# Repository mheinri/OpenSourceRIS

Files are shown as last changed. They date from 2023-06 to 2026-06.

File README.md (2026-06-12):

# Open Source RIS
An open source linearly polarized Reconfigurable Intelligent Surface (RIS) with 1-bit phase control for the frequency range of 5 GHz WiFi (5.15 - 5.875 GHz).

<p align="center">
  Open source RIS
  <br />
  Fig. 1: Open source RIS with 16×16=256 elements, front side
</p>

<p align="center">
  RIS backside
  <br />
  Fig. 2: Back side of the RIS with controller board attached
</p>

## Commercially Available Version
> [!NOTE]
> Due to the many inquiries we have received: An improved, ready-to-use version
> of this RIS for teaching, research, and development is commercially available
> from our startup **[NovoFlect](https://www.novoflect.de/en/)**.

- **Fully assembled, tested, and verified** - no need to deal with component
  sourcing, PCB procurement, assembly, soldering, or firmware flashing.
- **Compact variant** with 120 elements available.
- **Other frequency ranges** available as well, e.g. 3.6 GHz with 3-bit phase
  resolution or 28 GHz.
- Interested? Feel free to reach out via the contact form on our website:
  **[www.novoflect.de/en/contact](https://novoflect.de/en/contact/)**

## Unit Cell Design
The RIS unit cell consists of a linearly polarized pin-fed patch antenna, realized on a printed circuit board (PCB). Low-cost FR4 substrate with a specified dielectric constant of ϵr = 4.6 and dissipation factor tan δ = 0.028 is used. Fig. 3 shows the simplified unit cell with its dimensions. The circuit network generates a binary switchable reflection coefficient by using a BGS12P2L6 single pole, double throw (SPDT) RF switch from Infineon Technologies.

<p align="center">
  Simplified unit cell
  <br />
  Fig. 3: Simplified unit cell
</p>

## Surface Reflection Coefficient
The surface reflection coefficient of the RIS is measured with a vector network analyzer. During the measurement, the RIS is located in the aperture of a large horn antenna, which is specially designed for surface reflection coefficient measurements. Thus, the propagation vectors of the incident and reflected waves are perpendicular to the surface (normal incidence and reflection). Measuremetns are done for the two states where all elements are turned OFF or ON. A metal plate in size of the RIS is used for normalization of the measuements.
<p align="center">
  Measurement setup
  <br />
  Fig. 4: Setup for measurement of surface reflection coefficient
</p>

Fig. 5 shows the magnitude of the measured reflection coefficient. In the WiFi frequency bands from 5.15 - 5.875 GHz, the worst case surface reflection coefficient is −5.2 dB at 5.56 GHz for the OFF state and −4.8 dB at 5.15 GHz for the ON state.
<p align="center">
  Magnitude response
  <br />
  Fig. 5: Magnitude response
</p>

Fig. 6 shows the measured phase response as well as the phase difference between the all ON and all OFF states. The phase difference is wrapped to values between 0° and 180° and reaches its maximum at 5.53 GHz. It is worse at 5.875 GHz with a value of 92°.
<p align="center">
  Simplified unit cell
  <br />
  Fig. 6: Phase response and phase difference
</p>

## Power Supply
Power is supplied either via USB or via an external voltage source, e.g. a power supply unit, a battery or a rechargeable accumulator. The external voltage can be supplied via a coaxial power connector (2.1 x 5.5 mm), where the positive potential is applied to the inner pin of the connector. The recommended voltage range is between 9 V and 24 V DC. Power consumption with all elements ON as approx. 2 W.

The external voltage can be measured and read out, see documentation of the corresponding command below. This can be used, for example, to monitor the charge level of a battery.

## Control Interfaces
A controller board is attached to the back side of the RIS. With this, the RIS can be connected to a PC and controlled via a USB connection. Alternatively, it can be operated wirelessly with a battery and controlled via Bluetooth Low Energy (BLE). Fig. 7 shows the block diagram of the control unit.

<p align="center">
  Block diagram
  <br />
  Fig. 7: Block diagram
</p>

### USB interface
When using the USB interface, a virtual COM port (VCP) driver for the FT231XS USB-to-UART converter has to be installed. If the driver is not already installed or does not install automatically, it can be downloaded from the homepage of manufacturer FTDI (currently available at [https://ftdichip.com/drivers/vcp-drivers/](https://ftdichip.com/drivers/vcp-drivers/)). The VCP driver is provided for Windows, Linux and Mac OS.

Settings for the virtual COM port are as follows:
* 8 data bits
* 0 parity bits
* 1 stop bit
* 115.2 kBd/s

### BLE interface
A Proteus-III Bluetooth module from Würth Elektronik is used for control via Bluetooth. This is configured as a Bluetooth peripheral and must be coupled with a Bluetooth central, for example a PC with a Bluetooth interface installed. If the RIS is supplied with power, a new Bluetooth device appears in the search list of the PC. The device identifier or Bluetooth name of the RIS has the format A-xxxxxx, where xxxxxx stands for three bytes of the MAC address of the Bluetooth module in hexadecimal format (e.g. A-3163D1). These three bytes can be taken from the label on the Bluetooth module as "ID". The green LED next to the Bluetooth module flashes as long as the module has not been paired and is in advertising mode.

If pairing is started, a Static Pass Key must be entered. That Key hast to be set in advance via the USB interface and the `!BT-Key` command described below. If the pairing was successful, the green LED next to the Bluetooth module lights up permanently.

After pairing, the write and read services of the Bluetooth protocol must be activated in order to exchange data with the Bluetooth module. Once the services have been activated, the red LED next to the Bluetooth module lights up continuously. How exactly the services are activated depends on the software used to control the Bluetooth interface on the PC. Example code for MATLAB is provided under [Software/Control Software/MATLAB Code Examples](/Software/Control%20Software/MATLAB%20Code%20Examples/).

### Command syntax
All commands are ASCII encoded and are therefore easy to read. Each command starts with an exclamation mark (`!`) or a question mark (`?`) as start character followed by the actual command content. The command is then terminated at the end with a newline character (`␤`). A response from the RIS starts with a number sign (`#`) and is terminated with a newline cahracter as well. It is not necessary to be case sensitive with commands.

The following commands are available:
* Setting a pattern: `!0x...`
* Reading the currently configured pattern: `?Pattern`
* Reading the external supply voltage: `?Vext`
* Reading the serial number: `?SerialNo`
* Resetting the RIS: `!Reset`
* Setting the Static Pass Key for Bluetooth: `!BT-Key`

#### Setting a pattern
Each RIS element has been assigned a number between 1 and 256. Looking at the front of the surface as in Fig. 1, the first element is located in the top left corner. The other elements are arranged in reading direction with ascending number.
Examples: The second element is to the right of the first element, the 16th element is in the top right corner, the 17th element is on the far left in the second row from the top, and the 256th element is the one in the bottom right corner.
Essentially, a 256-bit number is sent to the RIS as a control command. Here, each bit represents the state of a specific RIS element. With a 0, the corresponding element is deactivated and the LED on the back is not lit and with a 1, the element is activated and the LED lights up. The assignment of the bit indices to the unit cells can be taken from the table below.

|Bit-Index|255 (MSB)|254|253|...|2|1|0 (LSB)|
|---|---|---|---|---|---|---|---|
|**Element no.**|1|2|3|...|254|255|256|

The control command for setting a pattern is formed on the basis of this 256-bit number. The command starts with an exclamation mark (`!`) as start character, followed by the 256-bit number in hexadecimal format. The hex prefix (`0x`) is specified at the beginning for better readability. The command is then terminated with a newline character (`␤`) at the end.

|Example Command|Set Pattern|
|---|---|
|`!0x0000000000000000000000000000000000000000000000000000000000000000␤`|All elements inactive|
|`!0xFFFFFFFFFFFFFFFFFFFFFFFFFFFFFFFFFFFFFFFFFFFFFFFFFFFFFFFFFFFFFFFF␤`|All elements active|
|`!0x8000000000000000000000000000000000000000000000000000000000000000␤`|Element 1 active|
|`!0x0000000000000000000000000000000000000000000000000000000000000001␤`|Element 256 active|
|`!0xFF00FF00FF00FF00FF00FF00FF00FF00FF00FF00FF00FF00FF00FF00FF00FF00␤`|Left half of the RIS active|
|`!0xFFFFFFFFFFFFFFFFFFFFFFFFFFFFFFFF00000000000000000000000000000000␤`|Upper half of the RIS active|

If the pattern was set successfully, the RIS sends `#OK␤` as confirmation. If no response is sent by the RIS, either an invalid command was used or an error occurred. In this case, the configured pattern of the RIS remains unchanged.

#### Reading the currently configured pattern
To read out the currently set pattern, the command `?Pattern␤` is used. The RIS then responds with `#0X012...DEF␤`, where `012...DEF` is a hexadecimal 256-bit long number. The structure of this number is the same as for setting a pattern.

|Example Command|Example Response from RIS|
|---|---|
|`?Pattern␤`|`#0X00007FFE40025FFA500A57EA542A55AA55AA542A57EA500A5FFA40027FFE0000␤`|

#### Reading the external supply voltage
In order to read out the external supply voltage that is present at the coaxial power connector, the command `?Vext␤` is used. The RIS then responds with `#00.00 V␤`, where `00.00` is a fixed-point number for the measured voltage in Volts.

|Example Command|Example Response from RIS|
|---|---|
|`?Vext␤`|`#09.14 V␤`|

#### Reading the serial number
Reading the serial number of a RIS board is done by sending the `?SerialNo␤` command. The RIS then responds with `#SerNo: 123␤`, where `123` is a fixed length serial number of up to three digits. For serial numbers with less digits, leding spaces are transmitted as well.

|Example Command|Example Response from RIS|
|---|---|
|`?SerialNo␤`|`#SerNo:  12␤`|

#### Resetting the RIS
The RIS can be reset by sending the `!Reset` command. The microcontroller then performs a software reset. The RIS is back up as soon as a `#READY␤` is received at the end of the boot information.

An example full response of the RIS after resetting or power cycling is as follows:
```
␤
Open Source RIS␤
Firmware version: 1.1␤
Serial no.:  12␤
Row count: 16␤
Column count: 16␤
␤
#READY!␤
```

Note that an established Bluetooth connection gets lost during a reset, so that a reinitialization of the BLE connection is required.

#### Setting the Static Pass Key for Bluetooth
The Static Pass Key can only be set via the USB interface. This command cannot be executed via Bluetooth. The Static Pass Key is non-volatile and remains unchanged after power cycling the RIS or resetting it via the `!Reset` command.
To set the Static Pass Key, the command `!BT-Key=123456␤` is used, where `123456` is exemplary for the new Key. The Static Pass Key has a fixed length of six decimal digits, all of which must be specified. Valid is therefore a number between zero and 999999.

|Example Command|New Static Pass Key|
|---|---|
|`!BT-Key=000000␤`|000000|
|`!BT-Key=123456␤`|123456|
|`!BT-Key=054860␤`|054860|

If the Static Pass Key was set successfully, the RIS sends `#OK␤` as confirmation. If the RIS sends `#ERROR␤`, either an invalid key was specified or an error occurred. Time between sending the command and receiving the response may take several seconds.

## Publications
* M. Heinrichs, A. Sezgin and R. Kronberger, "Open Source Reconfigurable Intelligent Surface for the Frequency Range of 5 GHz WiFi," 2023 IEEE International Symposium On Antennas And Propagation (ISAP), Kuala Lumpur, Malaysia, 2023, pp. 1-2, [doi: 10.1109/ISAP57493.2023.10389095.](https://doi.org/10.1109/ISAP57493.2023.10389095)
* M. Heinrichs, F. Pirlet and R. Kronberger, "Measurement System and Methodology for RIS-Evaluation," 2023 IEEE International Symposium On Antennas And Propagation (ISAP), Kuala Lumpur, Malaysia, 2023, pp. 1-2, [doi: 10.1109/ISAP57493.2023.10388696.](https://doi.org/10.1109/ISAP57493.2023.10388696)

## Acknowledgment
Many thanks to the Institute of Electronic Circuits at Ruhr University Bochum for the extensive help with assembling the printed circuit boards.
This work was funded by the German Federal Ministry of Education and Research (BMBF) in the framework of Project MetaSec (Förderkennzeichen 16KIS1236).

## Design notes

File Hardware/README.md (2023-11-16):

# Manufacturing Information
Open Source RIS is designed for the JLC04161H-7628 impedance-controlled PCB stackup from JLCPCB ([jlcpcb.com](https://jlcpcb.com/)). It is highly recommended to use the same manufacturer and PCB stackup for the RF PCB in order to get comparable results! For the controller PCB any suitable 4-layer PCB stackup may be used.

Recommended PCB stackup is as follows:

|Copper-Layer|Material|Thickness|Layer Usage (RF PCB)|Layer Usage (Controller PCB)|
|-|-|-|-|-|
|1|Copper + gold plating|0.035 mm|Signals and components|Signals and components|
| |FR4 (7628 material)|0.210 mm| | |
|2|Copper|0.015 mm|Groundplane|Groundplane|
| |FR4 (core material)|1.065 mm| | |
|3|Copper|0.015 mm|Empty (copper removed)|+3.3 V|
| |FR4 (7628 material)|0.210 mm| | |
|4|Copper + gold plating|0.035 mm|Patches|Signals|

Dielectric constant of prepreg material and core material must be equal:
* Dielectric constant (according to manufacturer): 4.6
* Dielectric constant (measured and used for simulation): 4.8

PCB assembly was done in-house and not with JLCPCB assembly service. Small changes to the pick and place file format may be required for commercial assembly services.

# Settings for Ordering at JLCPCB
The following order options have been used when ordering from JLCPCB. Irrelevant options are omitted.
## RF PCB
* Base Material: FR4
* Layers: 4
* Dimension: 360 mm * 247 mm
* Product Type: Industrial/Consumer electronics
* Different Design: 1
* Delivery Format: Single PCB
* PCB Thickness: 1.6 mm
* Impedance Control: Yes JLC04161H-7628
* Material Type: TG155
* Via Covering: Tented
* Surface Finish: ENIG Gold Thickness 1 U'' (ENIG is preferred over HASL)
* Deburring/Edge routing: No
* Outer Copper Weight: 1 oz
* Inner Copper Weight: 0.5 oz
* Gold Fingers: No
* Flying Probe Test: Fully Test
* Castellated Holes: No
* Remove Order Number: Yes (but is not required)
* Min via hole size/diameter: 0.2 mm/(0.3/0.35 mm)
* 4-Wire Kelvin Test: Yes
* Paper between PCBs: Yes (but is not required)
* Appearance Quality: IPC Class 2 Standard
* Silkscreen Technology: Ink-Jet/Screen Printing Silkscreen
* Board Outline Tolerance: +/- 0.2 mm (Regular)

## Controller PCB
Same as above with Dimension 105 mm * 95 mm. Impedance controlled stackup is not required as the controller PCB is not relevant for the RF properties.

# Known Issue
It has been observed that in some cases the board-to-board connections do not work. Due to its large size, the RF PCB is not absolutely planar. By mounting the RIS, e.g. on an aluminum frame, the RF PCB bends. This affects the pin header connection, causing it to fail in some cases.

We have therefore soldered the controller PCB directly to the RF PCB by omitting the female pin heads. The distance between RF PCB and controller PCB should remain at least 3 mm to avoid undesirable effects on the RIS elements below.

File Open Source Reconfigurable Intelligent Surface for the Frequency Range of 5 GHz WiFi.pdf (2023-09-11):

# Open Source Reconfigurable Intelligent Surface for the Frequency Range of 5 GHz WiFi

Markus Heinrichs
High Frequency Laboratory
TH Koeln - University of Appl. Sciences Cologne, Germany
markus.heinrichs@th-koeln.de

Aydin Sezgin
Institute of Digital Communication Systems Ruhr University Bochum
Bochum, Germany
aydin.sezgin@rub.de

Rainer Kronberger
High Frequency Laboratory
TH Koeln - University of Appl. Sciences Cologne, Germany
rainer.kronberger@th-koeln.de

Abstract—Reconfigurable Intelligent Surfaces (RIS) have been identified as a potential ingredient to enhance the performance of contemporary wireless communication and sensing systems. Yet, most of the existing devices are either costly or not available for reproduction. To close this gap, a Reconfigurable Intelligent Surface for the frequency range of 5 GHz WiFi is presented in this work. We describe the designed unit cell, which is optimized for the full frequency range of 5.15 to 5.875 GHz. Standard FR4 substrate is used for cost optimization. The measured reflection coefficient of a rectangular RIS prototype with 256 elements is used for RF performance evaluation. Fabrication data and firmware source code are made open source, which makes RIS more available in real measurement setups.
Index Terms—Reconfigurable Intelligent Surface, RIS, unit cell, WiFi, open source
I. INTRODUCTION
Reconfigurable Intelligent Surfaces (RIS) are currently a major subject of research on wireless systems. Multiple potential application areas of RIS are being investigated around the world, from next generation cellular networks (6G) through unmanned aerial vehicle assisted systems to physical layer security systems [1] [2]. Nevertheless, the availability of RIS prototypes is still limited, which does not allow every research group to perform experiments in real measurement setups using RIS. In particular, the large amount of time required to develop a RIS can be a time-consuming and costly impediment. In order to facilitate the access to measurements with RIS, we have made our 5.5 GHz RIS design open source, similar to the OpenRIS for 3.5 GHz from [3]. The fabrication data is freely accessible and can be used without restriction, which enables everyone to build and utilize RIS. The frequency range of 5 to 6 GHz is chosen since measurements at sub-6 GHz frequencies are cost effective and widespread, not least because of their use in WiFi. The wavelength of approx. 55 mm at a center frequency of 5.5 GHz results in a size ratio that allows arrays with several hundred elements while at the same time being manufacturable with acceptable effort.
In the following, we describe our RIS unit cell and its principle of operation. Then we address the RF performance and present measurement results.

II. UNIT CELL
The RIS unit cell consists of a rectangular patch reflector above a ground plane. The patch on the front side is connected to the back side of the RIS by a plated through-hole connection (via), as in the case of a linearly polarized pin-fed patch antenna. We realized this by using a printed circuit board (PCB) with three copper layers, which can be manufactured externally in a standard process as a four-layered PCB with the second layer left empty. Thus, the unit cell can be implemented on a single PCB on which the components can be placed and soldered by machines, facilitating manufacturing. We used a low-cost FR4 substrate with a specified dielectric constant of ϵr = 4.6 and dissipation factor tan δ = 0.028. A cross sectional view of the unit cell and its dimensions are depicted

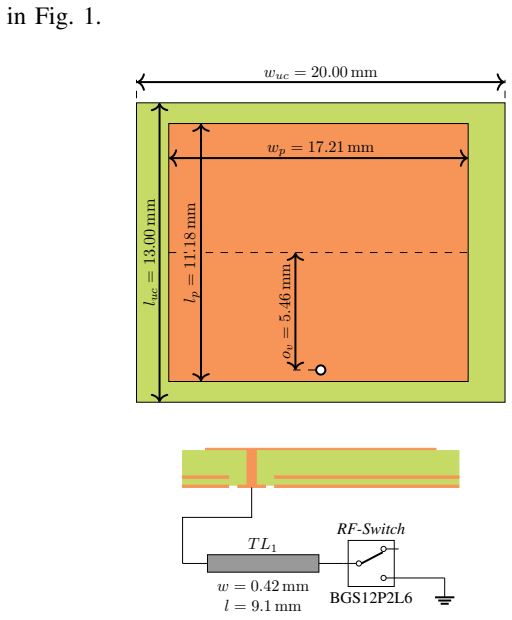
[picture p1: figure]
in Fig. 1.; wuc = 20.00 mm; luc = 13.00 mm; RF-Switch; BGS12P2L6

Fig. 1. Unit cell dimensions and schematic

The shown circuit network is located on the back side of the unit cell and generates a binary switchable reflection coefficient. For this we use a BGS12P2L6 single pole, double throw (SPDT) RF switch in CMOS technology from Infineon Technologies [4], which switches the antenna port to either an open or short circuit. In this way, a phase shift of 180◦ is achieved while keeping the DC power consumption of the RF switches at a low level. The microstrip transmission line

T L1 is used to tune the RF performance. Our unit cell is optimized for the WiFi frequency range of 5.15 to 5.875 GHz. This means, that the magnitude of the reflection coefficient of the surface should be as large as possible in both switching states, with the propagation direction of the incident and reflected wave being directed orthogonal to the surface (normal incidence and reflection). The phase difference between the two switching states is optimized to be as close as possible to the ideal value of 180◦ over the whole frequency range considered. By using these optimization goals, the resulting transmission line T L1 has a width of w = 0.42 mm and a length of l = 9.1 mm. Simulation and optimization of the unit cell is done in CST Microwave Studio using Floquet ports and frequency domain solver.
The fabricated RIS, which consists of 16 × 16 unit cells, is shown in Fig. 2. A controller PCB is attached to the backside. This allows the RIS to be connected to a PC and controlled via a USB connection. Alternatively, it can be operated wirelessly with a battery and controlled via Bluetooth Low Energy (BLE).

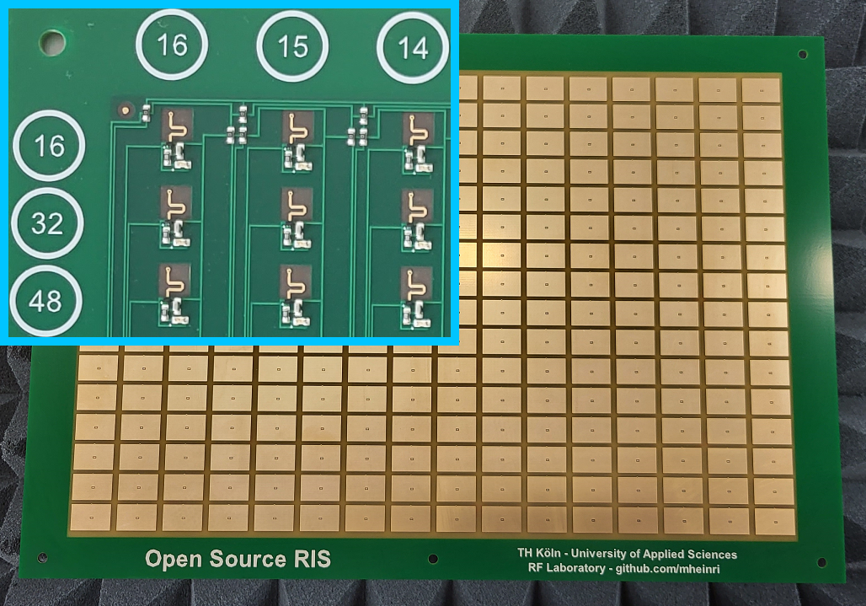
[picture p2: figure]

Fig. 2. RIS with 256 elements and sectional view of nine backside elements

III. RF MEASUREMENTS
The reflection coefficient of the RIS is measured with a vector network analyzer while the RIS is located in the aperture of a horn antenna, which is specially designed for the measurement of surface reflection coefficients. The magnitude of the measured surface reflection coefficient is shown in Fig. 3 (top). The measurement is normalized to the reflection of a metal plate in the size of the RIS. The corresponding phase as well as the phase difference between the two states in which all elements are turned OFF or ON are shown in Fig. 3 (bottom). The phase difference is wrapped to values between 0

◦

and 180◦
In the WiFi frequency bands, the minimum surface reflection coefficient is −5.2 dB at 5.56 GHz for the OFF state and −4.8 dB at 5.15 GHz for the ON state. This could be improved slightly by using low-loss RF substrate, however, with a significant increase of material costs. The phase difference reaches its maximum of 180◦
at 5.53 GHz and is minimal with

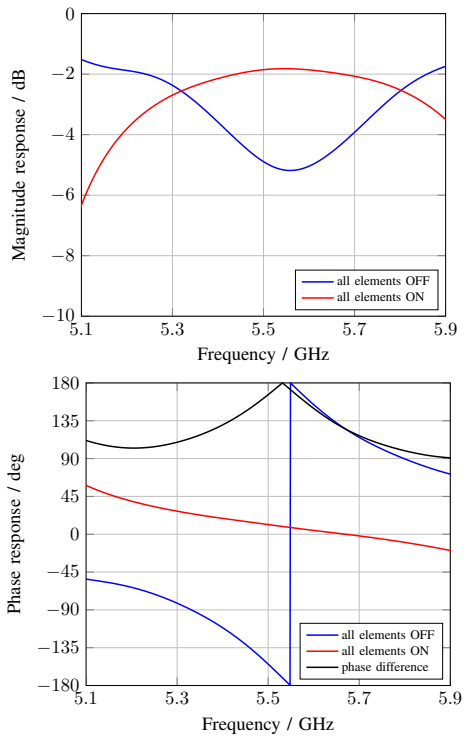
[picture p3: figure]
Frequency / GHz; Magnitude response / dB; all; elements OFF; elements ON; Phase response / deg; all phase difference

Fig. 3. Surface reflection coefficient (magnitude, phase and phase difference)

a value of 92◦
at 5.875 GHz. It is under current investigation how this phase behaviour performs in practical systems.

IV. CONCLUSION
We have presented an open source RIS for the frequency bands of 5 GHz WiFi. It offers a worse-case reflection coefficient of −5.2 dB and a phase response between 92◦ and
180◦ over the whole frequency range considered. The RIS is low cost and easy to manufacture. It can be controlled easily and is enabled for wireless usage. Fabrication data, firmware source code and additional documentation for the presented open source RIS are accessible at GitHub [5].
V. ACKNOWLEDGMENT
This work was funded by the German Federal Ministry of Education and Research (BMBF) in the framework of Project MetaSec (Forderkennzeichen 16KIS1235 and 16KIS1236). ¨

REFERENCES

[1] C. Pan et al., “Reconfigurable Intelligent Surfaces for 6G Systems: Principles, Applications, and Research Directions,” in IEEE Communications Magazine, vol. 59, no. 6, pp. 14-20, June 2021, doi: 10.1109/MCOM.001.2001076.
[2] Y. Li, C. Yin, T. Do-Duy, A. Masaracchia and T. Q. Duong, “Aerial Reconfigurable Intelligent Surface-Enabled URLLC UAV Systems,” in IEEE Access, vol. 9, pp. 140248-140257, 2021, doi: 10.1109/AC-CESS.2021.3119268.
[3] J. Rains, https://www.github.com/jimrains/OpenRIS, (accessed June 09 2023).
[4] Infineon Technologies, ”BGS12P2L6 - SPDT general purpose switch for high power applications”, BGS12P2L6 datasheet, Rev. 2.0, Jul. 2019.
[5] M. Heinrichs, https://www.github.com/mheinri, (accessed June 29 2023).

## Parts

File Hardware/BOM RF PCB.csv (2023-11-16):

Part | Value | Size | Quantity | Manufacturer | Manufacturer part number | Name
Pinhead | 2x2 | SMD RM1.27 | 2 | Würth Elektronik | 62100421021 | J1-2
Pinhead | 2x5 | SMD RM1.27 | 2 | Würth Elektronik | 62101021021 | J3-4
C | 1nF | 0603 | 256 | Würth Elektronik | 885012006029 | C001-256
C | 100nF | 0603 | 32 | Würth Elektronik | 885012206071 | C257-288
IC | 74HC595BQ | DHVQFN16 | 32 | Nexperia | 74HC595BQ,115 | IC257-288
LED | Green | 0603 | 256 | Würth Elektronik | 150060VS75000 | LED001-256
R | 0R | 0603 | 301 | Yageo | AC0603FR-070RL | R257-557
R | 1.5kR | 0603 | 256 | Yageo | RC0603FR-071K5L | R001-256
RF-Switch | BGS12P2L6 | TSLP-6 | 256 | Infineon | BGS12P2L6E6327XTSA1 | IC001-256

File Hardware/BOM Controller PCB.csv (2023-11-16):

Part | Value | Size | Quantity | Manufacturer | Manufacturer part number | Name
S | Switch | / | 1 | CTS | 222CMVABR | S101
X | Mini-USB connector | / | 1 | Würth Elektronik | 65100516121 | X202
X | DC-Jack | / | 1 | Würth Elektronik | 694106106102 | X201
Q | Crystal 25MHz | HC49UP | 1 | IQD | LFXTAL070480Reel | Q101
Pinhead | 1x06 | SMD RM2.54 | 1 | Amphenol FCI | 10129380-906002ALF | J101
Pinhead | 2x2 | RM 1.27 | 2 | Würth Elektronik | 62200421821 | J401, J402
Pinhead | 2x5 | RM 1.27 | 2 | Würth Elektronik | 62201021821 | J403, J404
LED | Yellow | 0603 | 1 | Würth Elektronik | 150060YS75000 | LED101
LED | Blue | 0603 | 1 | Würth Elektronik | 150060BS75000 | LED102
LED | Red | 0603 | 2 | Würth Elektronik | 150060RS75000 | LED201, LED301
LED | Green | 0603 | 2 | Würth Elektronik | 150060VS75000 | LED202, LED302
IC | LM1117IMP-3.3 | SOT223 | 1 | Texas Instruments | LM1117IMP-3.3/NOPB | IC203
IC | STM32F446RET6 | LQFP64 | 1 | STMicroelectronics | STM32F446RET6 | IC101
IC | FT231XS-R | SSOP20 | 1 | FTDI | FT231XS-R | IC202
IC | LM2596DSADJG | D˛PAK | 1 | onsemi | LM2596DSADJG | IC201
MOD | Protheus-III | / | 1 | Würth Elektronik | 2611011024000 | MOD301
D | SK33 | DO214AB | 4 | Micro Comm. Comp. | SK33-TP | D201, D202, D203, D204
L | Ferrite | 0805 | 3 | Würth Elektronik | 742792012 | L202, L301, L302
L | 100ľH | 8x8 | 1 | Würth Elektronik | 74404086101 | L201
C | 100ľF | 8x10.5 | 1 | Panasonic | EEH-ZA1V101V | C202
C | 680ľF | 8x11.9 | 1 | Panasonic | 16SVPK680M | C203
C | 10ľF | 1210 | 5 | Würth Elektronik | 885012209028 | C204, C209, C215, C216, C304
C | 4.7ľF | 0805 | 1 | TDK | C2012X7R1H475K125AC | C109
C | 1ľF | 0805 | 3 | AVX | 08051C105K4Z2A | C104, C106, C301
C | 100nF | 0603 | 15 | Würth Elektronik | 885012206071 | C103, C105, C107, C108, C110, C111, C201, C205, C207, C210, C213, C214, C217, C302, C305
C | 10nF | 0603 | 2 | Würth Elektronik | 885012206065 | C206, C208
C | 47pF | 0603 | 2 | Würth Elektronik | 885012006055 | C211, C212
C | 22pF | 0603 | 2 | Würth Elektronik | 885012006053 | C101, C102
C | 22pF | 0402 | 1 | Würth Elektronik | 885012005057 | C303
R | 0R | 0805 | 4 | Yageo | RC0805FR-070RL | R101, R102, R104, R105
R | 27R | 0603 | 2 | Yageo | RC0603FR-0727RL | R205, R206
R | 3.3kR | 0603 | 7 | Yageo | RC0603FR-073K3L | R107, R108, R204, R207, R208, R301, R302
R | 10kR | 0603 | 2 | Yageo | RC0603FR-0710KL | R103, R203
R | 13kR | 0603 | 1 | Yageo | RC0603FR-0713KL | R202
R | 91kR | 0603 | 1 | Yageo | RC0603FR-0791KL | R201

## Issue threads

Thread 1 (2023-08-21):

Regarding Hardware Design

DDS2144, 2023-08-21:
Dear Sir,

I'm currently working on hardware design using your repository and facing challenges. Could I kindly request your expert guidance on some queries? I've attached relevant files for your reference.

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
[Doubt-1 - Controller_PCB.xlsx](https://github.com/mheinri/OpenSourceRIS/files/12393408/Doubt-1.-.Controller_PCB.xlsx)
[Doubt-2 - Controller_PCB.xlsx](https://github.com/mheinri/OpenSourceRIS/files/12393409/Doubt-2.-.Controller_PCB.xlsx)
[Doubt-3 - RF_PCB.xlsx](https://github.com/mheinri/OpenSourceRIS/files/12393410/Doubt-3.-.RF_PCB.xlsx)
[Doubt-4 - RF_PCB.xlsx](https://github.com/mheinri/OpenSourceRIS/files/12393412/Doubt-4.-.RF_PCB.xlsx)

mheinri, 2023-08-21:
Hi DDS2144 ,
there is no information on the pinhead positions as they get populated by hand. This is beacuse these parts are through-hole components rather than SMD parts.
Resistor R106 is not populated at all (n.p.), thus there is no information in the BOM.
Fiducials are only used for automatic placement of components by the pick-and-place machine, so there is also no additional information on it required.
Hope this is helpful.
Best regards!

Closed 2023-08-21.

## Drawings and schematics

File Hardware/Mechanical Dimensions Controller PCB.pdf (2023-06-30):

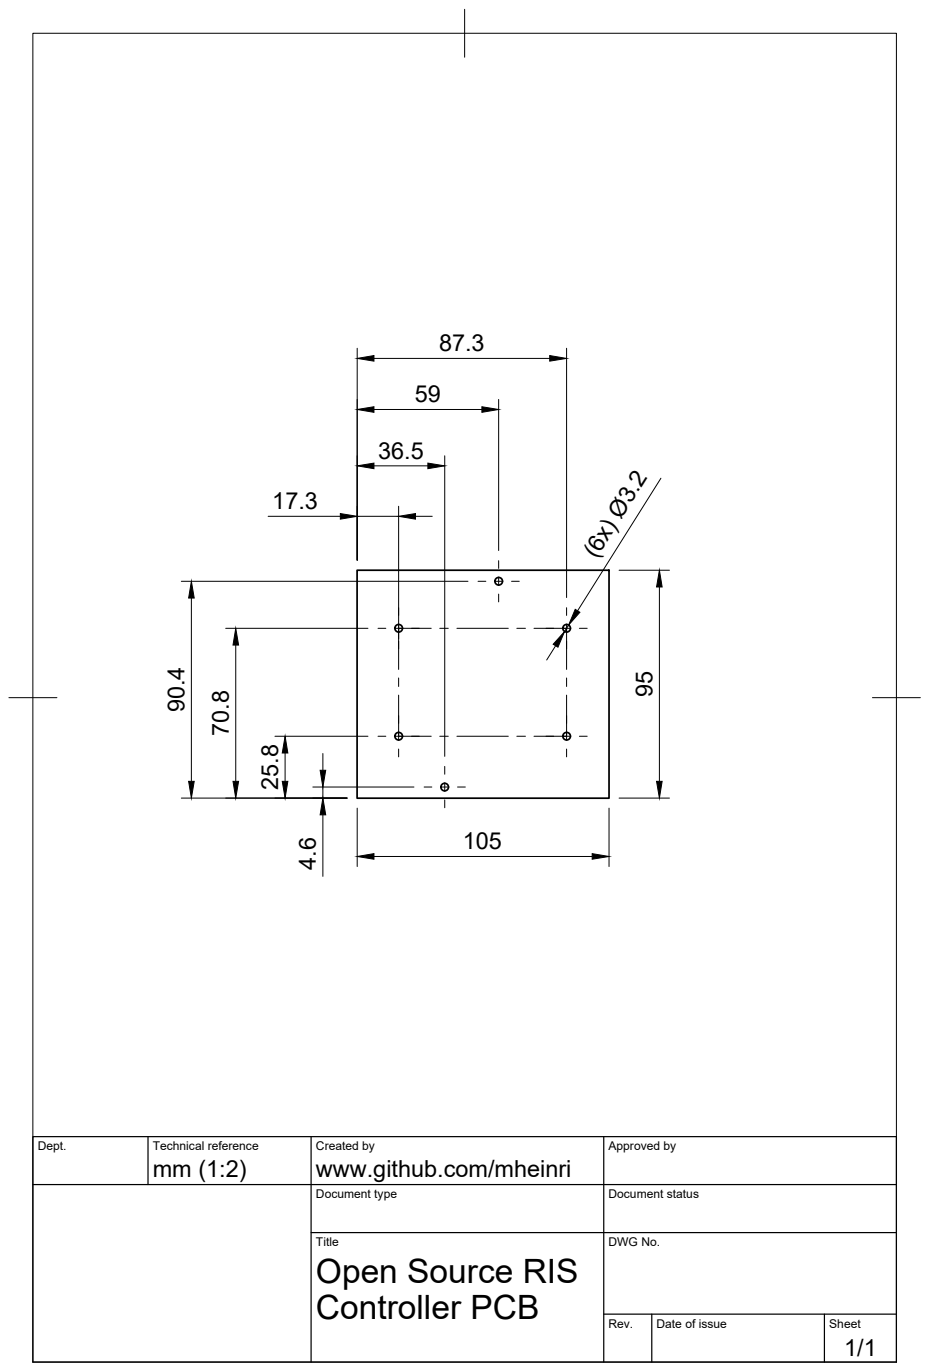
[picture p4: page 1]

Dept. | Technical reference mm (1:2) | Created by www.github.com/mheinri | Approved by

Document type | Document status

Title Open Source RIS Controller PCB | DWG No.

Rev. | Date of issue | Sheet 1/1

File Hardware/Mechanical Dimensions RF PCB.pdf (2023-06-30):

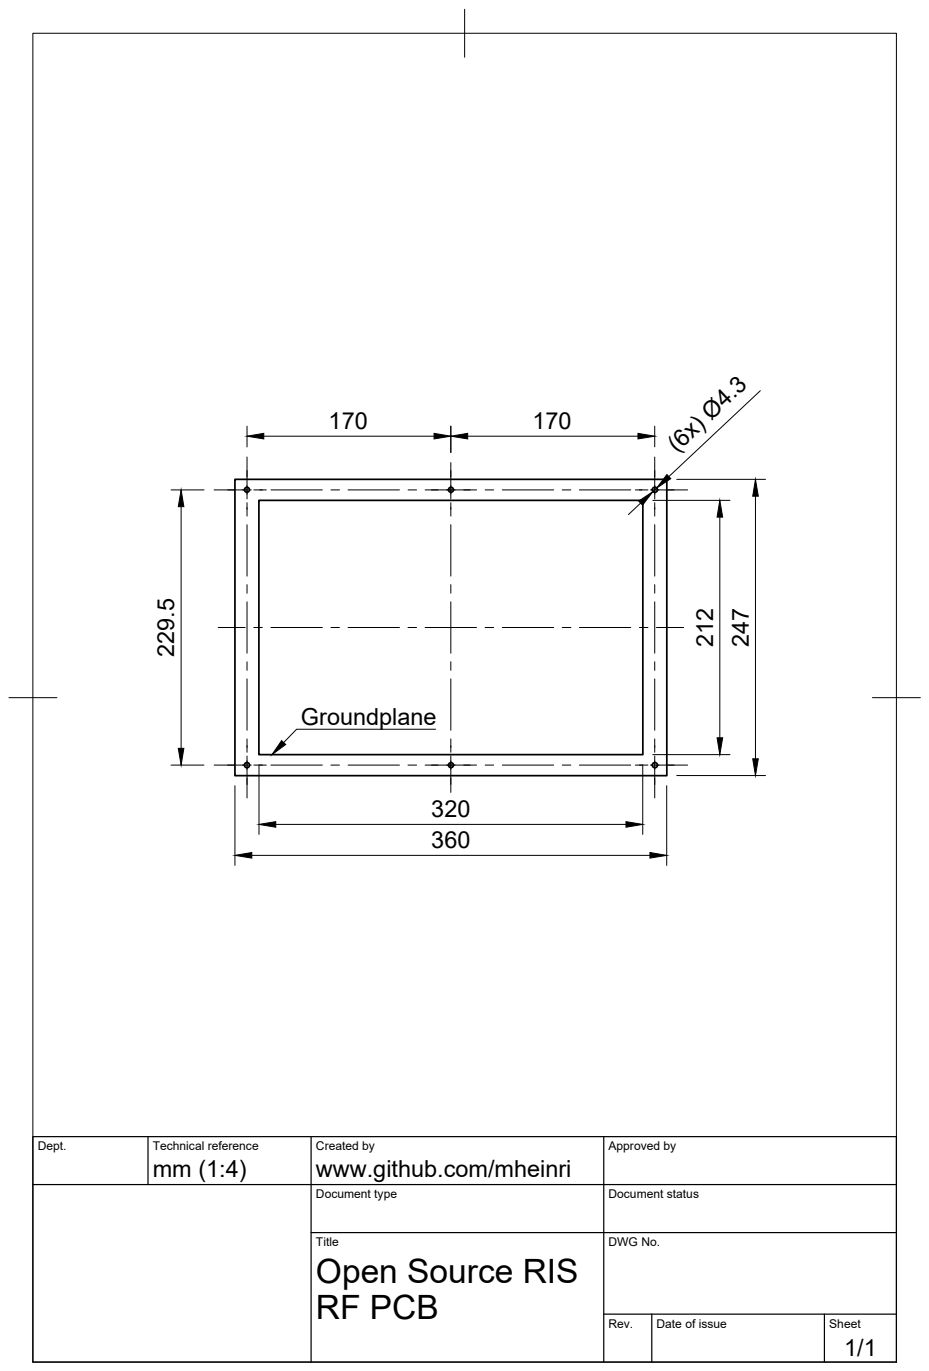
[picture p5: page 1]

Dept. | Technical reference mm (1:4) | Created by www.github.com/mheinri | Approved by

Document type | Document status

Title Open Source RIS RF PCB | DWG No.

Rev. | Date of issue | Sheet 1/1

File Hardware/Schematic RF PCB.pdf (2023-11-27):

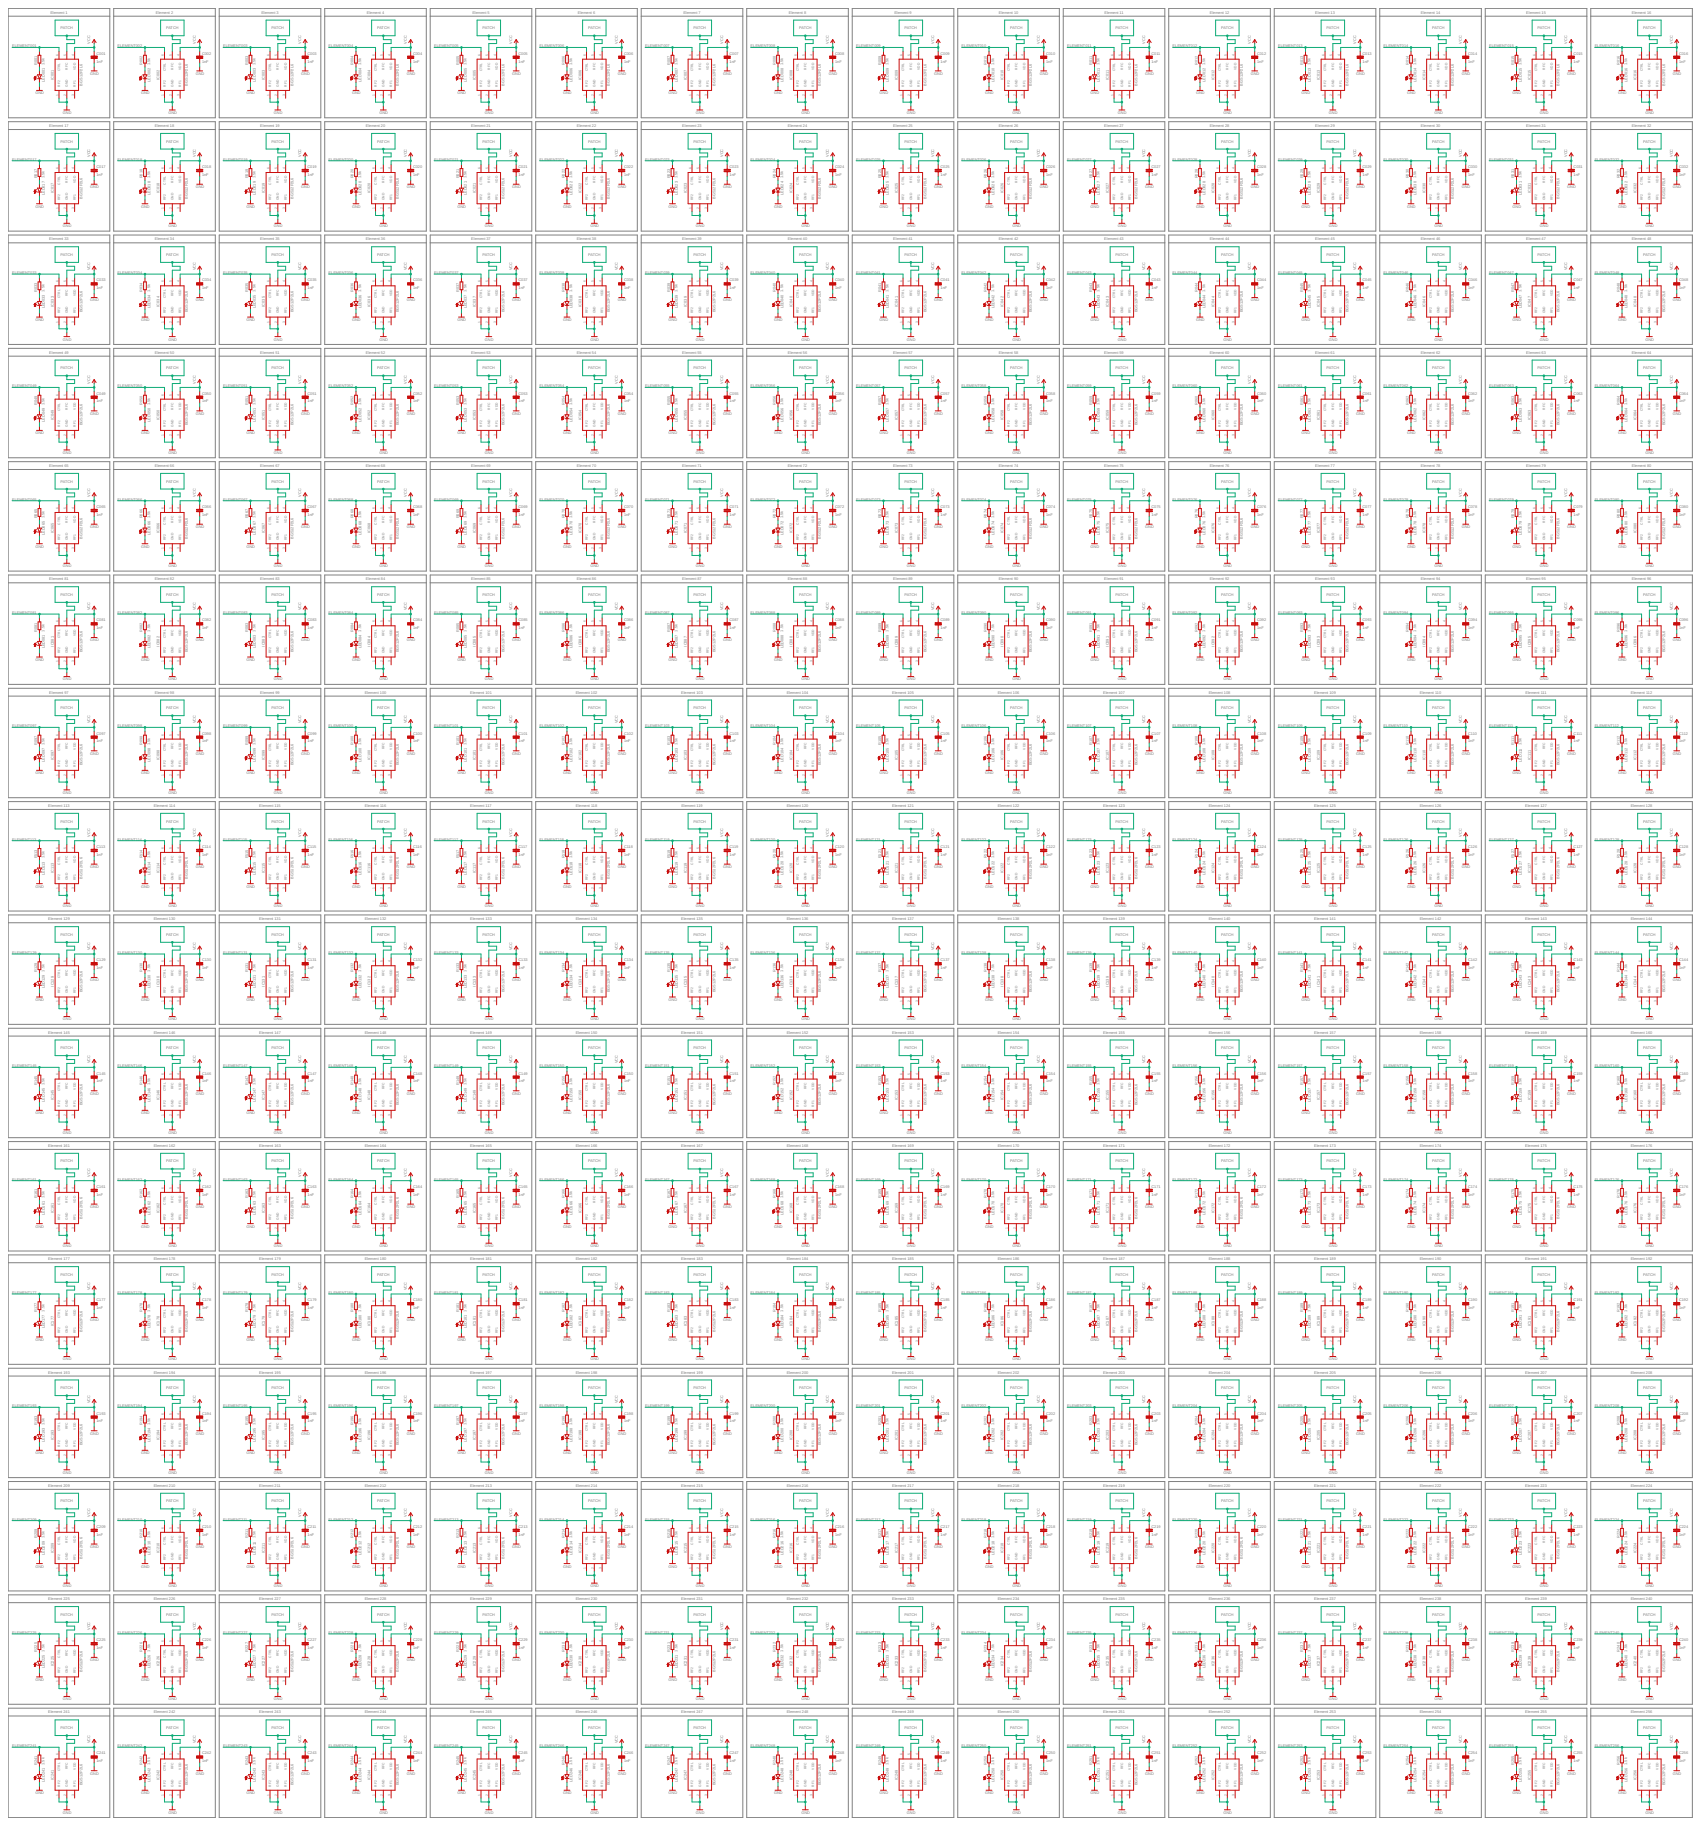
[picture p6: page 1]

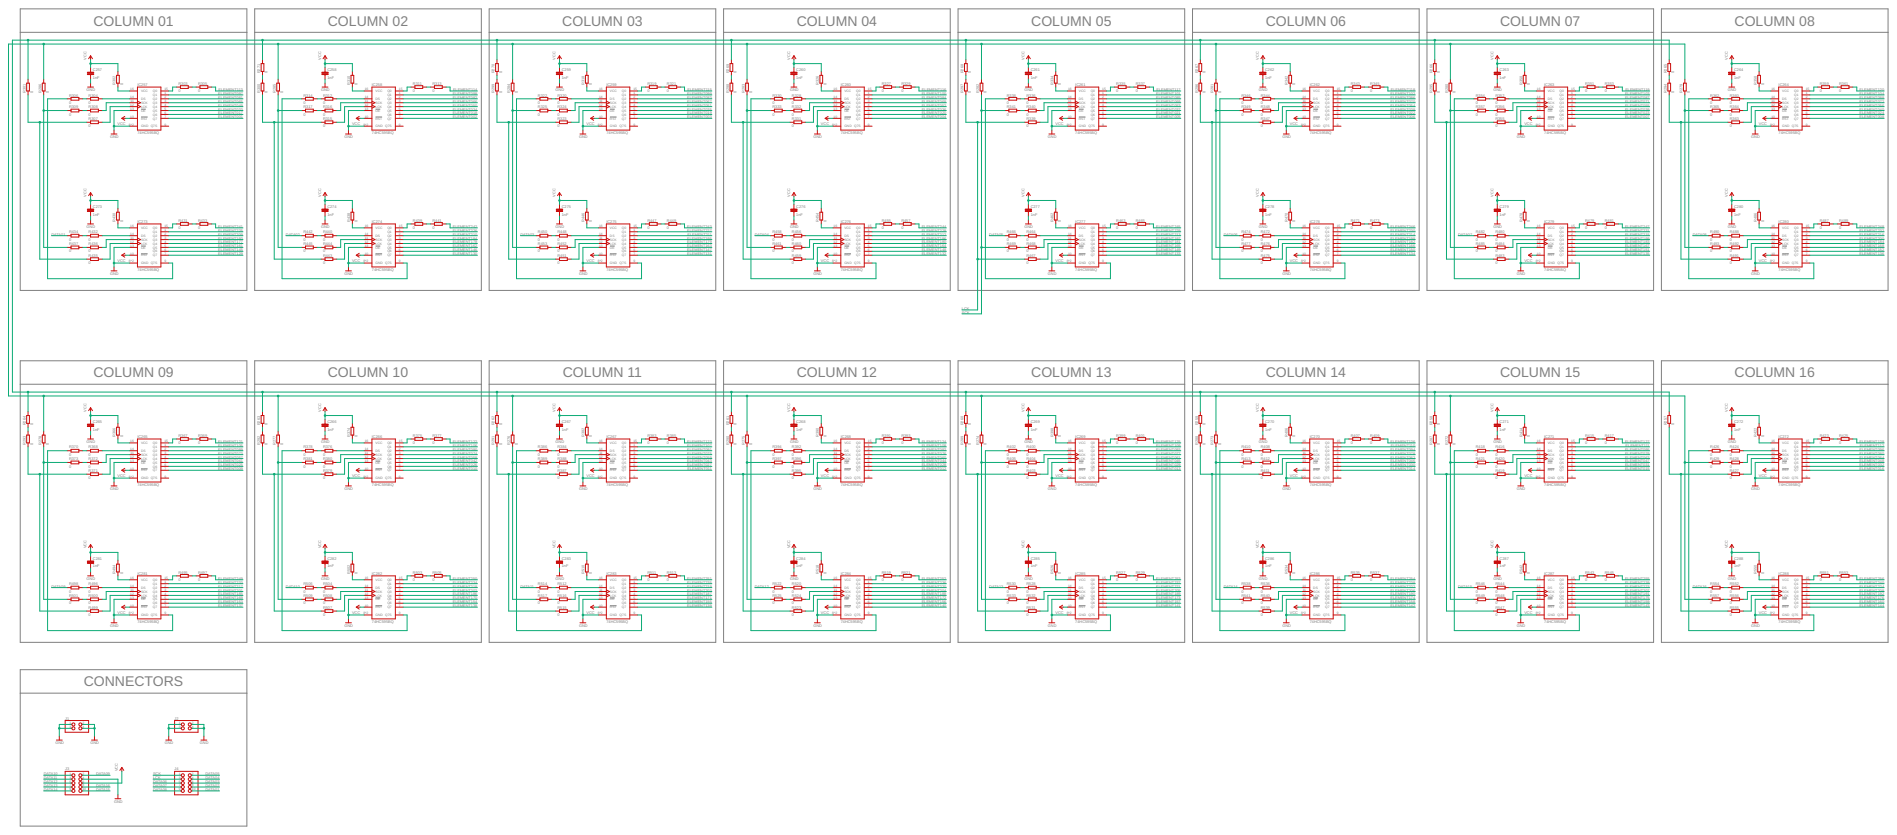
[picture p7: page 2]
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

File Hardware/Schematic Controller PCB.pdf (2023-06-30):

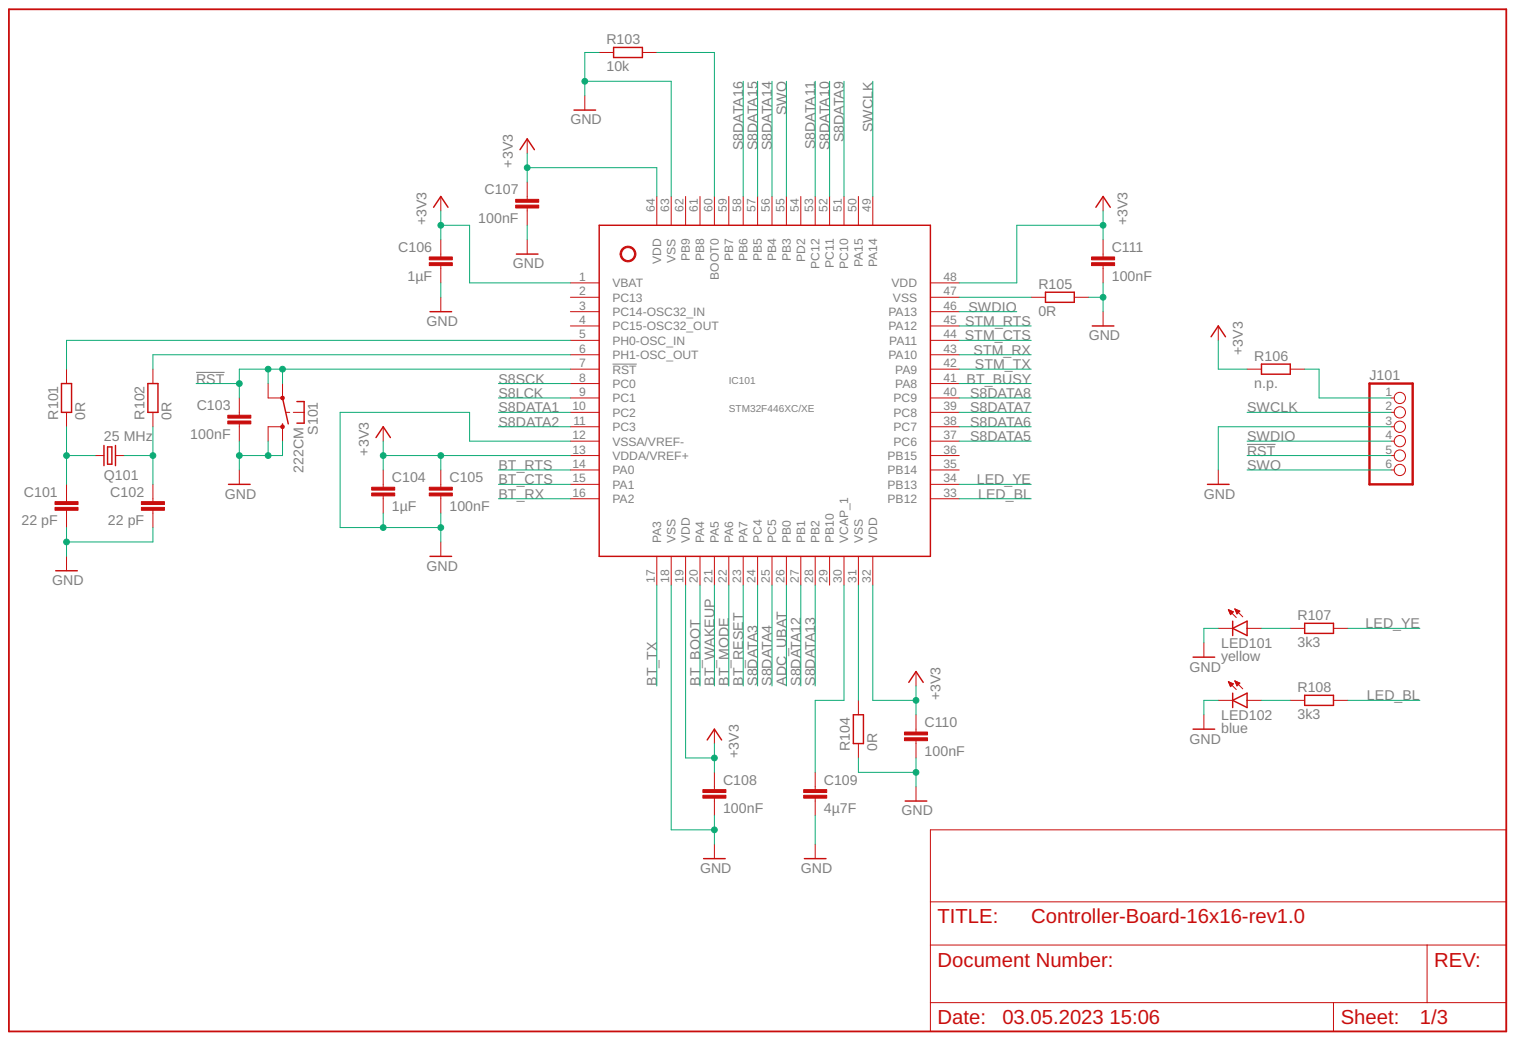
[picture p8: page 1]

Document Number: | REV:

Date: 03.05.2023 15:06 | Sheet: 1/3

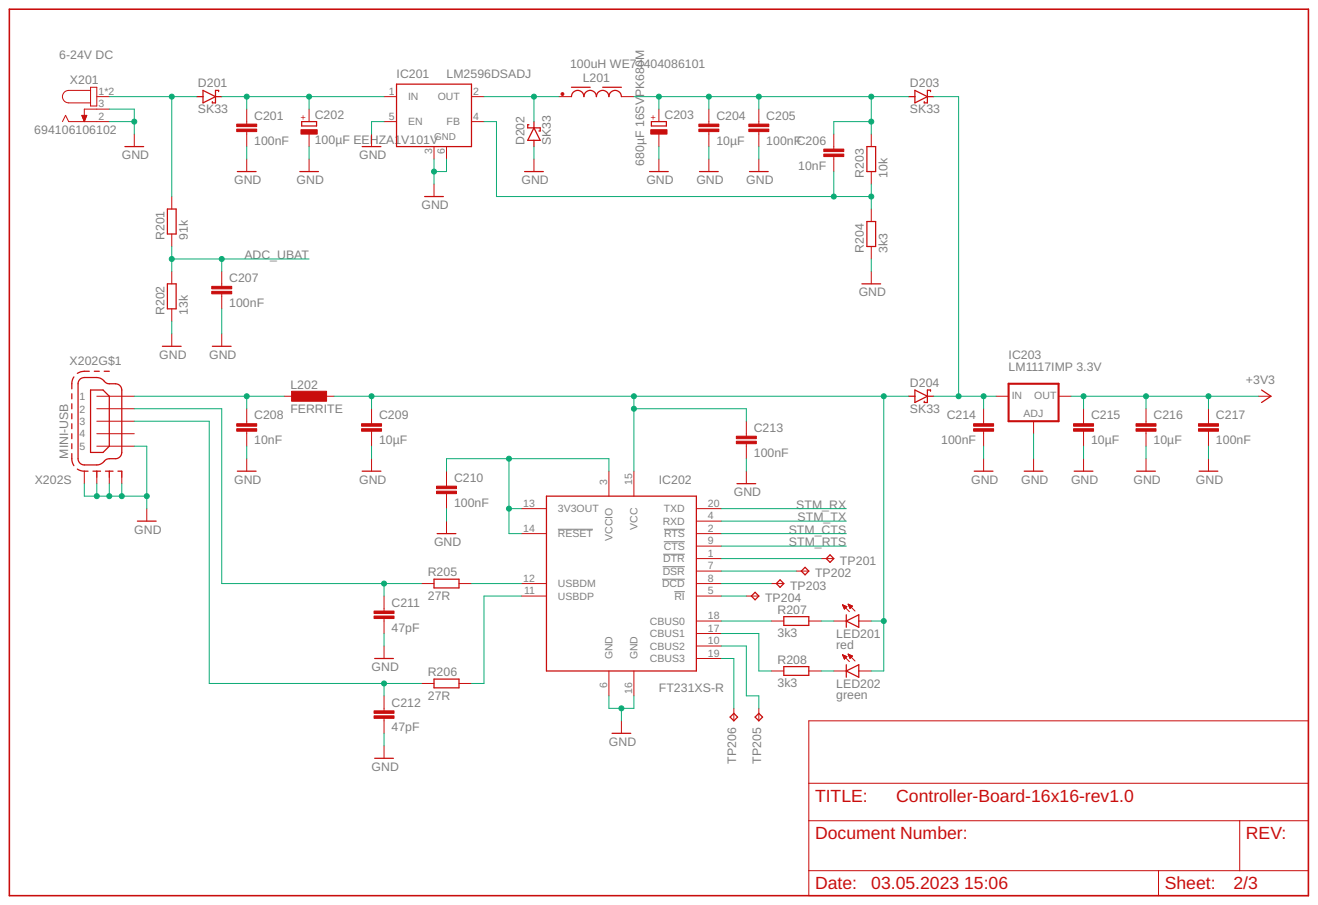
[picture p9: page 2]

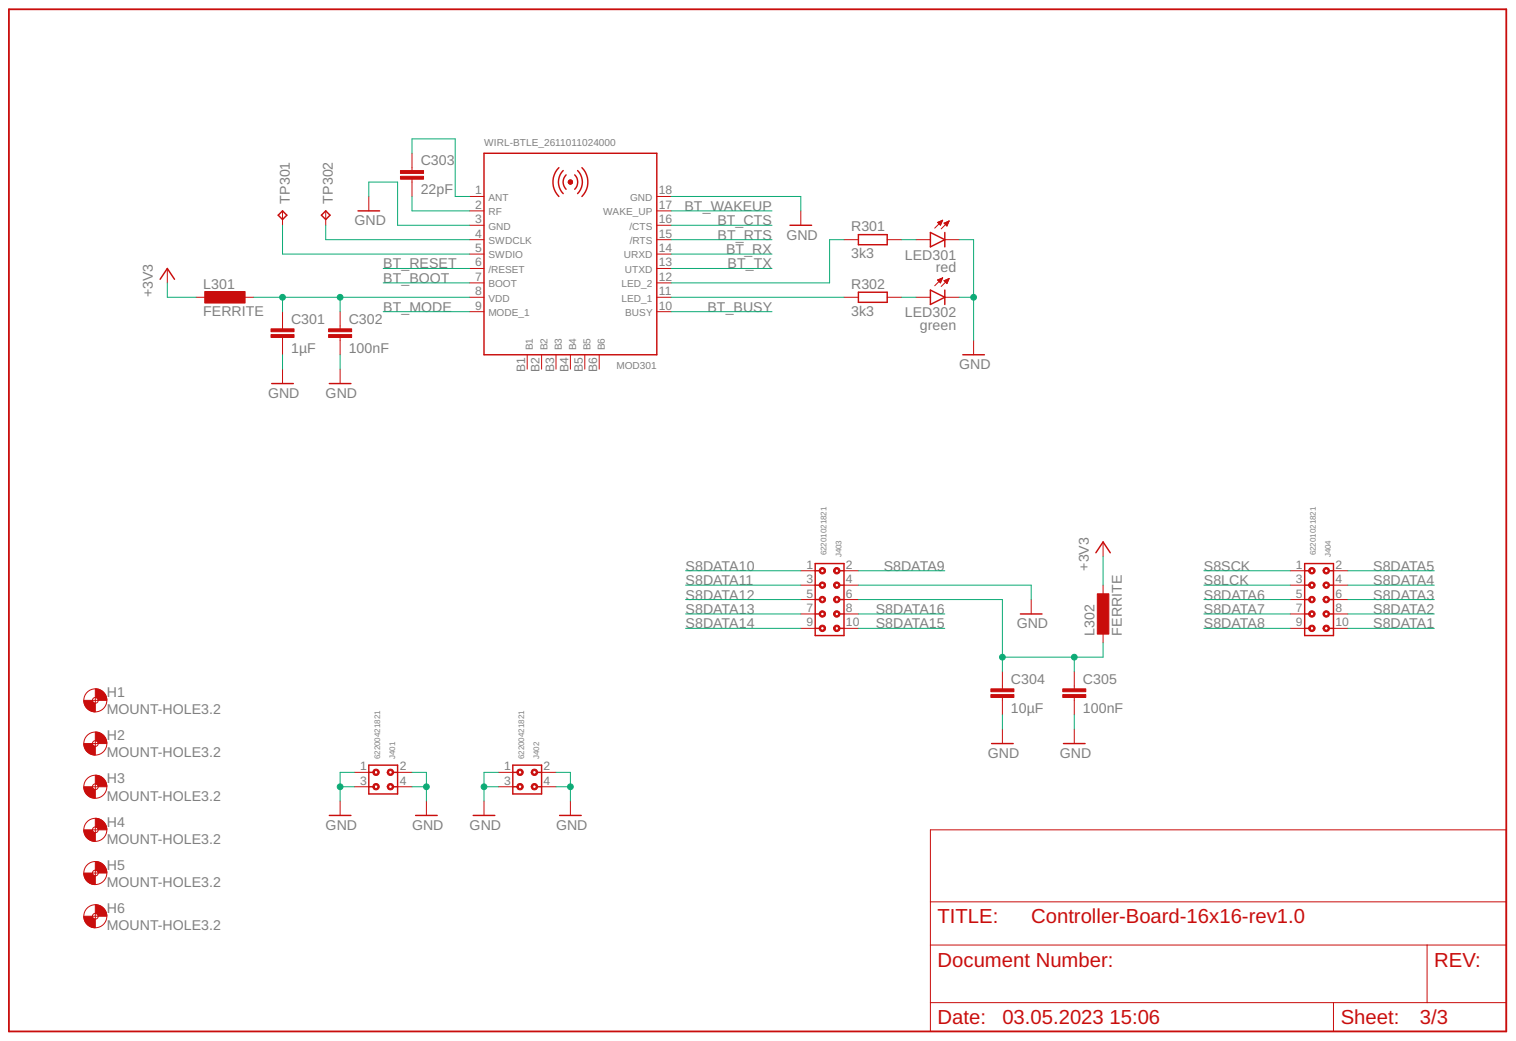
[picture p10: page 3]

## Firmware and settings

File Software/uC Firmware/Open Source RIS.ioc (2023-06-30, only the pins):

Mcu.UserName=STM32F446RCTx
PA0-WKUP.Signal=USART2_CTS
PA1.Signal=USART2_RTS
PA10.Signal=USART1_RX
PA11.Signal=USART1_CTS
PA12.Signal=USART1_RTS
PA2.Signal=USART2_TX
PA3.Signal=USART2_RX
PA4.GPIO_Label=BT_BOOT
PA4.Signal=GPIO_Output
PA5.GPIO_Label=BT_WAKEUP
PA5.Signal=GPIO_Output
PA6.GPIO_Label=BT_MODE
PA6.Signal=GPIO_Output
PA7.GPIO_Label=BT_RESET
PA7.Signal=GPIO_Output
PA8.GPIO_Label=BT_BUSY
PA8.Signal=GPIO_Input
PA9.Signal=USART1_TX
PB0.Signal=ADCx_IN8
PB1.GPIO_Label=S8DATA12
PB1.Signal=GPIO_Output
PB12.GPIO_Label=LED-BL
PB12.Signal=GPIO_Output
PB13.GPIO_Label=LED-YE
PB13.Signal=GPIO_Output
PB2.GPIO_Label=S8DATA13
PB2.Signal=GPIO_Output
PB4.GPIO_Label=S8DATA14
PB4.Signal=GPIO_Output
PB5.GPIO_Label=S8DATA15
PB5.Signal=GPIO_Output
PB6.GPIO_Label=S8DATA16
PB6.Signal=GPIO_Output
PC0.GPIO_Label=S8SCK
PC0.Signal=GPIO_Output
PC1.GPIO_Label=S8LCK
PC1.Signal=GPIO_Output
PC10.GPIO_Label=S8DATA9
PC10.Signal=GPIO_Output
PC11.GPIO_Label=S8DATA10
PC11.Signal=GPIO_Output
PC12.GPIO_Label=S8DATA11
PC12.Signal=GPIO_Output
PC2.GPIO_Label=S8DATA1
PC2.Signal=GPIO_Output
PC3.GPIO_Label=S8DATA2
PC3.Signal=GPIO_Output
PC4.GPIO_Label=S8DATA3
PC4.Signal=GPIO_Output
PC5.GPIO_Label=S8DATA4
PC5.Signal=GPIO_Output
PC6.GPIO_Label=S8DATA5
PC6.Signal=GPIO_Output
PC7.GPIO_Label=S8DATA6
PC7.Signal=GPIO_Output
PC8.GPIO_Label=S8DATA7
PC8.Signal=GPIO_Output
PC9.GPIO_Label=S8DATA8
PC9.Signal=GPIO_Output
PH0-OSC_IN.Signal=RCC_OSC_IN
PH1-OSC_OUT.Signal=RCC_OSC_OUT

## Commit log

2023-11-16 Update BOM Controller PCB.csv
    [BOM Controller PCB.csv]
2023-11-16 Update BOM RF PCB.csv
    [BOM RF PCB.csv]
